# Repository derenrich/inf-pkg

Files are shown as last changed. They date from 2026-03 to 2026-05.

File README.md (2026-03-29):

# E-Ink RP2040 Driver Board with weird extras

View it at [kicanvas](https://kicanvas.org/?repo=https%3A%2F%2Fgithub.com%2Fderenrich%2Finf-pkg).

# Based off of RP2040 Minimal Design for JLCPCB
Based on [Minimal design example](https://datasheets.raspberrypi.com/rp2040/Minimal-KiCAD.zip) referenced in [Hardware design with RP2040: Using RP2040 microcontrollers to build boards and products](https://datasheets.raspberrypi.com/rp2040/hardware-design-with-rp2040.pdf).  Design updated for KiCAD 7 and manufacture/assembly at JLCPCB.

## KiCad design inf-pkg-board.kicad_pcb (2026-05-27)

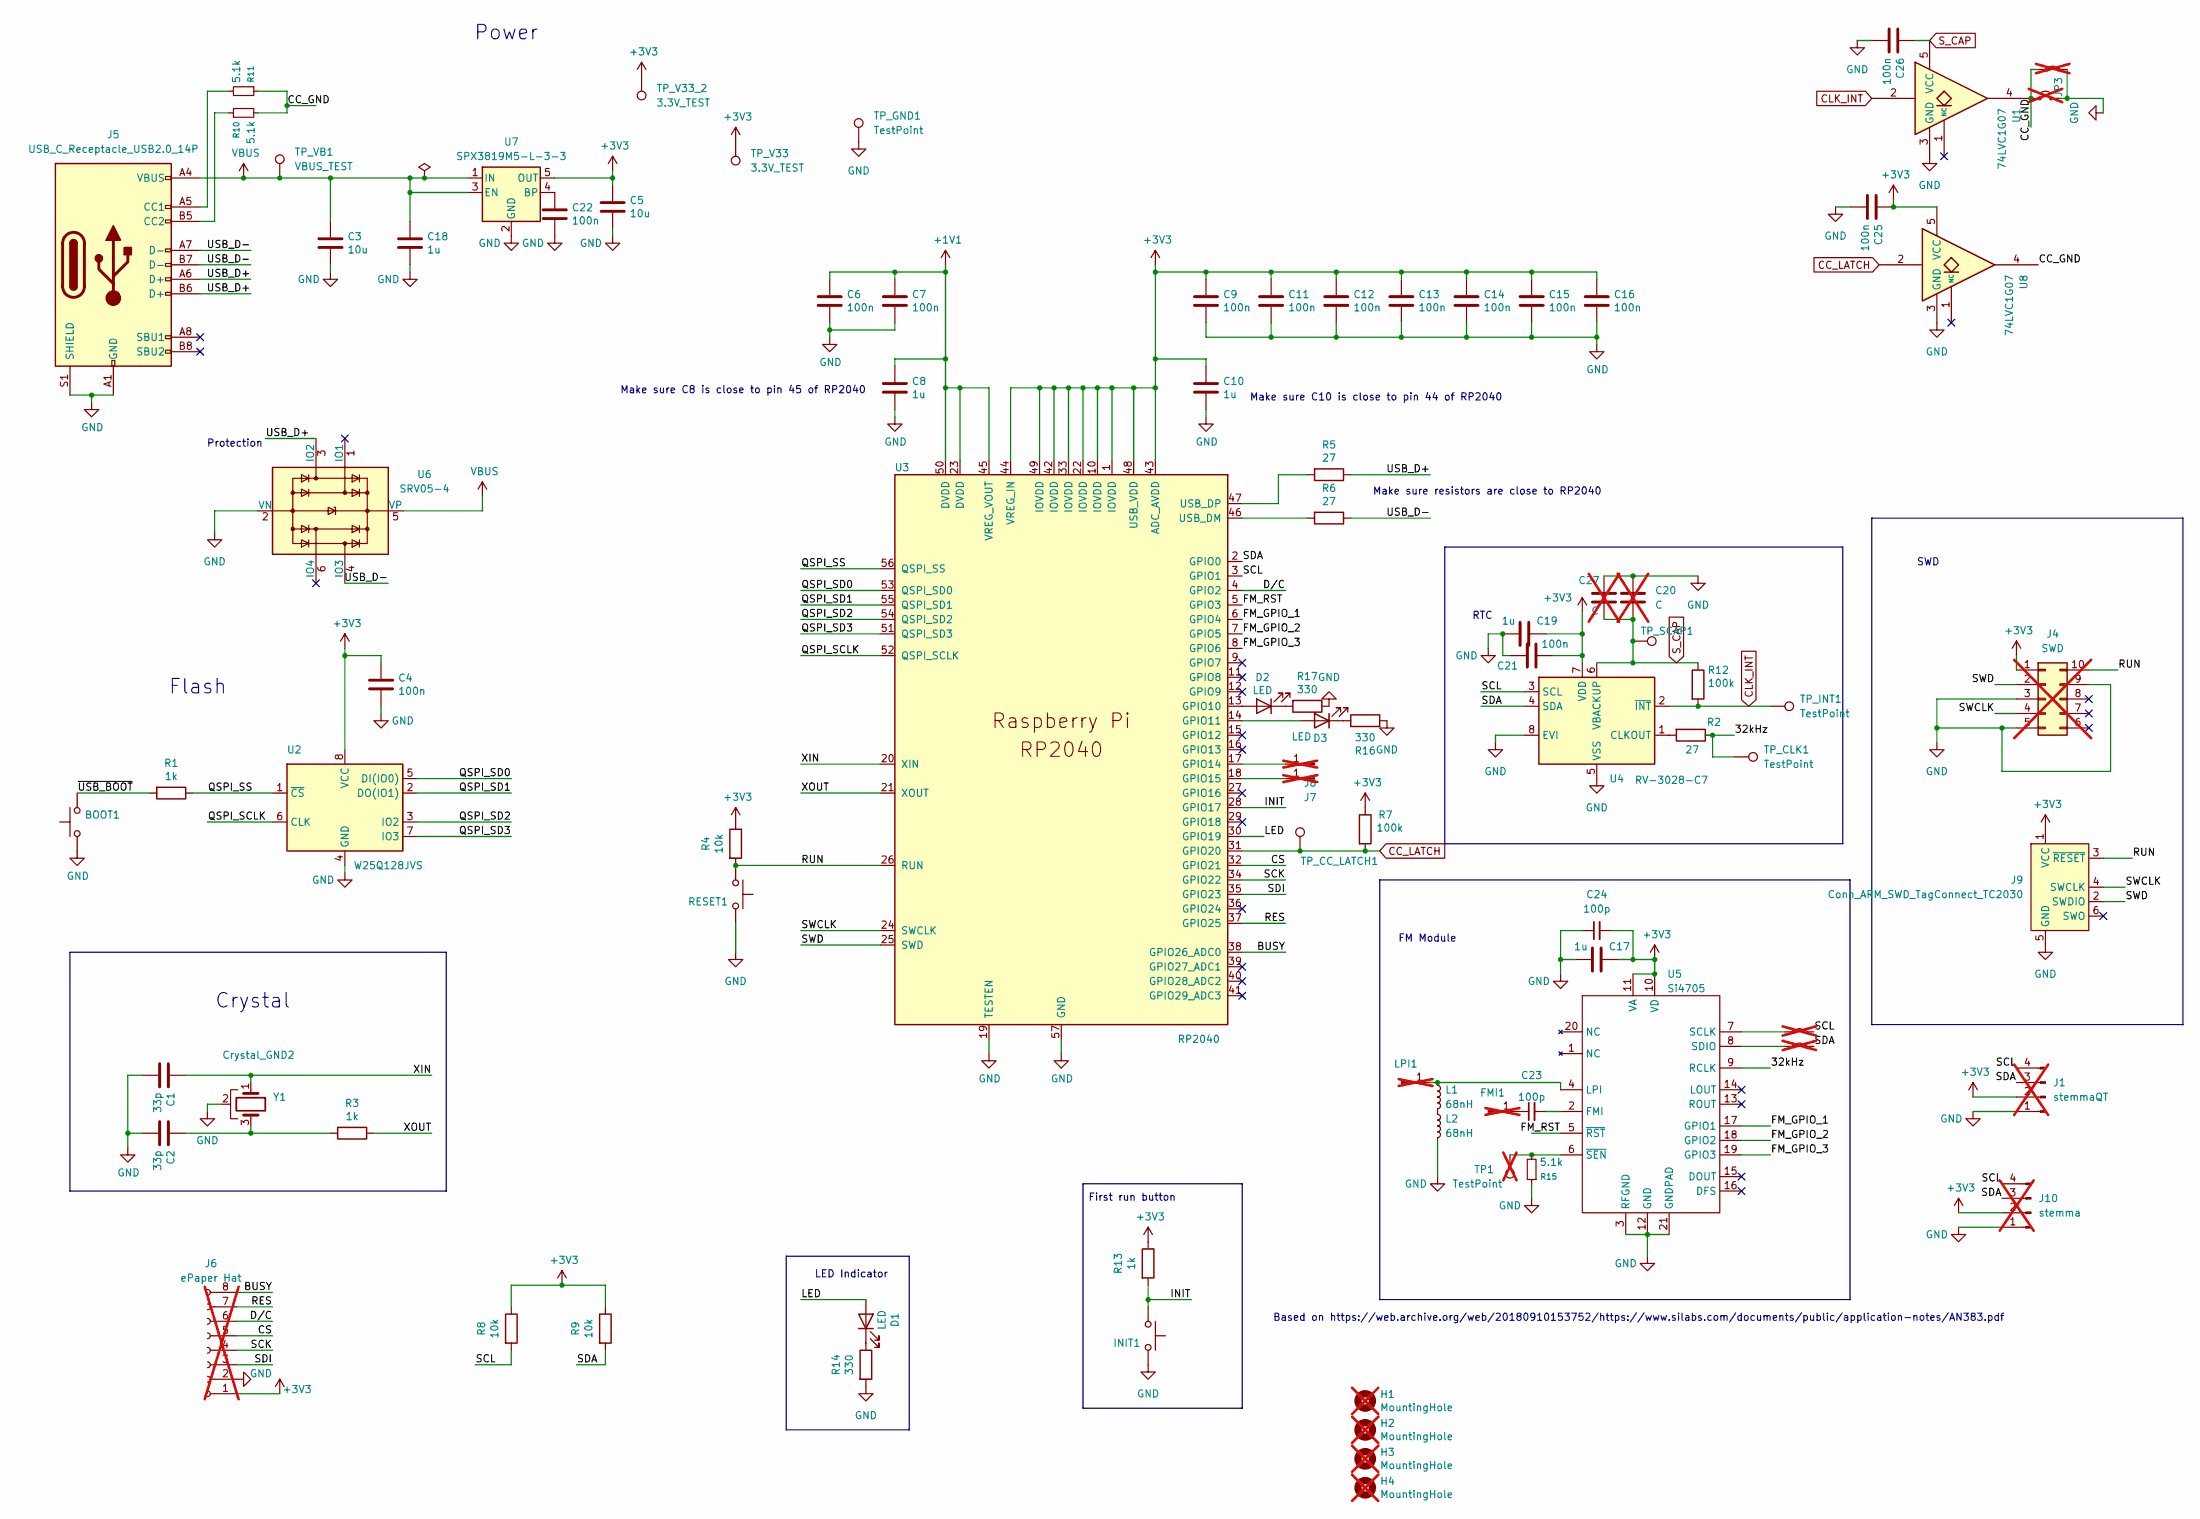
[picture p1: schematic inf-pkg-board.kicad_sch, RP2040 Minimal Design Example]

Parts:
BOOT1: TS-1088-AR02016; LCSC C720477
C1, C2: 33p; C_0402_1005Metric; LCSC C1562
C3, C5: 10u; C_0805_2012Metric; LCSC C15850
C4, C6, C7, C9, C11, C12, C13, C14, C15, C16, C21, C22, C25, C26: 100n; C_0402_1005Metric; LCSC C1525
C8, C10, C17, C18, C19: 1u; C_0402_1005Metric; LCSC C52923
C20: C; C_R21.00mm_P6.00mm; not fitted
C23, C24: 100p; C_0402_1005Metric; LCSC C1546
C27: C; C_Disc_D16.0mm_W5.0mm_P10.00mm; not fitted
D1, D2, D3: LED; D_0805_2012Metric; LCSC C84256
FMI1: Conn_01x01_Pin; PinHeader_1x01_P1.00mm_Vertical; not fitted
H1, H2, H3, H4: MountingHole; MountingHole_2.7mm_M2.5; not fitted
INIT1: TS-1088-AR02016; LCSC C720477
J1: stemmaQT; JST_PH_S4B-PH-K_1x04_P2.00mm_Horizontal; not fitted
J4: SWD; PinHeader_2x05_P1.27mm_Vertical_SMD; not fitted
J5: USB_C_Receptacle_USB2.0_14P; USB_C_Receptacle_G-Switch_GT-USB-7010ASV; LCSC C2988369
J6: ePaper Hat; PinHeader_1x08_P2.54mm_Vertical; not fitted
J7, J8: Conn_01x01_Pin; PinHeader_1x01_P2.54mm_Vertical; not fitted
J9: Conn_ARM_SWD_TagConnect_TC2030; Tag-Connect_TC2030-IDC-FP_2x03_P1.27mm_Vertical
J10: stemma; JST_PH_B4B-PH-K_1x04_P2.00mm_Vertical; not fitted
JP1, JP2: Jumper_2_Small_Bridged; SolderJumper-2_P1.3mm_Bridged_Pad1.0x1.5mm; not fitted
JP3: Jumper_2_Small_Open; PinHeader_1x02_P2.54mm_Vertical; not fitted
JP4: Jumper_2_Small_Bridged; SolderJumper-2_P1.3mm_Open_TrianglePad1.0x1.5mm; not fitted
L1, L2: 68nH; L_0603_1608Metric; LCSC C13415
LPI1: Conn_01x01_Pin; PinHeader_1x01_P2.54mm_Vertical; not fitted
R1, R3, R13: 1k; R_0402_1005Metric; LCSC C11702
R2, R5, R6: 27; R_0603_1608Metric; LCSC C25190
R4, R8, R9: 10k; R_0805_2012Metric; LCSC C17414
R7, R12: 100k; R_0402_1005Metric; LCSC C25741
R10, R11, R15: 5.1k; R_0402_1005Metric; LCSC C25905
R14, R16, R17: 330; R_0402_1005Metric; LCSC C25104
RESET1: TS-1088-AR02016; LCSC C720477
TP1: TestPoint; PinHeader_1x01_P1.00mm_Vertical; not fitted
TP_CC_LATCH1: TestPoint; TestPoint_Pad_D1.5mm
TP_CLK1: TestPoint; TestPoint_Pad_D1.5mm
TP_GND1: TestPoint; TestPoint_Pad_D1.5mm
TP_INT1: TestPoint; TestPoint_Pad_D1.5mm
TP_SCAP1: TestPoint; TestPoint_Pad_D2.5mm
TP_V33, TP_V33_2: 3.3V_TEST; TestPoint_Pad_D2.0mm
TP_VB1: VBUS_TEST; TestPoint_Pad_D2.0mm
U1, U8: 74LVC1G07; SOT-353_SC-70-5; LCSC C282345
U2: W25Q128JVS; SOIC-8_5.23x5.23mm_P1.27mm; LCSC C97521
U3: RP2040; RP2040-QFN-56; LCSC C2040
U4: RV-3028-C7; MicroCrystal_C7_SON-8_1.5x3.2mm_P0.9mm; LCSC C3019759
U5: Si4705; SiliconLabs_QFN-20-1EP_3x3mm_P0.5mm_EP1.8x1.8mm; LCSC C1526114
U6: SRV05-4; SOT-23-6; LCSC C85364
U7: SPX3819M5-L-3-3; SOT-23-5; LCSC C9055
Y1: Crystal_GND2; Crystal_SMD_3225-4Pin_3.2x2.5mm; LCSC C9002

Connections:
+1V1: C6.1, C7.1, C8.1, U3.23 (DVDD), U3.45 (VREG_VOUT), U3.50 (DVDD)
+3V3: C4.1, C5.1, C9.1, C10.1, C11.1, C12.1, C13.1, C14.1, C15.1, C16.1, C17.1, C19.1, C21.2, C24.2, C25.1, J1.2, J4.1, J6.1, J9.1 (VCC), J10.2, R4.1, R7.1, R8.1, R9.1, R13.1, TP_V33.1, TP_V33_2.1, U2.8 (VCC), U3.1 (IOVDD), U3.10 (IOVDD), U3.22 (IOVDD), U3.33 (IOVDD), U3.42 (IOVDD), U3.43 (ADC_AVDD), U3.44 (VREG_IN), U3.48 (USB_VDD), U3.49 (IOVDD), U4.7 (VDD), U5.10 (VD), U5.11 (VA), U7.5 (OUT), U8.5 (VCC)
/32kHz: R2.1, TP_CLK1.1, U5.9 (RCLK)
/BUSY: J6.8, U3.38 (GPIO26_ADC0)
/CC_GND: JP3.1 (A), JP4.1 (A), R10.2, R11.1, U1.4, U8.4
/CS: J6.5, U3.32 (GPIO21)
/D/C: J6.6, U3.4 (GPIO2)
/FM_GPIO_1: U3.6 (GPIO4), U5.17 (GPIO1)
/FM_GPIO_2: U3.7 (GPIO5), U5.18 (GPIO2)
/FM_GPIO_3: U3.8 (GPIO6), U5.19 (GPIO3)
/FM_RST: U3.5 (GPIO3), U5.5 (~RST)
/INIT: INIT1.1, R13.2, U3.28 (GPIO17)
/LED: D1.2 (A), U3.30 (GPIO19)
/QSPI_SCLK: U2.6 (CLK), U3.52 (QSPI_SCLK)
/QSPI_SD0: U2.5 (DI(IO0)), U3.53 (QSPI_SD0)
/QSPI_SD1: U2.2 (DO(IO1)), U3.55 (QSPI_SD1)
/QSPI_SD2: U2.3 (IO2), U3.54 (QSPI_SD2)
/QSPI_SD3: U2.7 (IO3), U3.51 (QSPI_SD3)
/QSPI_SS: R1.1, U2.1 (~CS), U3.56 (QSPI_SS)
/RES: J6.7, U3.37 (GPIO25)
/RUN: J4.10, J9.3 (~RESET), R4.2, RESET1.1, U3.26 (RUN)
/SCK: J6.4, U3.34 (GPIO22)
/SCL: J1.4, J10.4, JP1.2 (B), R8.2, U3.3 (GPIO1), U4.3 (SCL)
/SDA: J1.3, J10.3, JP2.2 (B), R9.2, U3.2 (GPIO0), U4.4 (SDA)
/SDI: J6.3, U3.35 (GPIO23)
/SWCLK: J4.4, J9.4 (SWCLK), U3.24 (SWCLK)
/SWD: J4.2, J9.2 (SWDIO), U3.25 (SWD)
/USB_D+: J5.A6 (D+), J5.B6 (D+), R5.1, U6.3 (IO2)
/USB_D-: J5.A7 (D-), J5.B7 (D-), R6.1, U6.4 (IO3)
/XIN: C1.1, U3.20 (XIN), Y1.1
/XOUT: R3.1, U3.21 (XOUT)
/~USB_BOOT: BOOT1.2, R1.2
CC_LATCH: R7.2, TP_CC_LATCH1.1, U3.31 (GPIO20), U8.2
CLK_INT: R12.2, TP_INT1.1, U1.2, U4.2 (~INT)
GND: BOOT1.1, C1.2, C2.2, C3.2, C4.2, C5.2, C6.2, C7.2, C8.2, C9.2, C10.2, C11.2, C12.2, C13.2, C14.2, C15.2, C16.2, C17.2, C18.2, C19.2, C20.1, C21.1, C22.2, C24.1, C25.2, C26.2, C27.1, INIT1.2, J1.1, J4.3, J4.5, J4.9, J5.A1 (GND), J5.A12 (GND), J5.B1 (GND), J5.B12 (GND), J5.S1 (SHIELD), J6.2, J9.5 (GND), J10.1, JP3.2 (B), JP4.2 (B), L2.2, R14.2, R15.1, R16.2, R17.1, RESET1.2, TP_GND1.1, U1.3 (GND), U2.4 (GND), U3.19 (TESTEN), U3.57 (GND), U4.5 (VSS), U4.8 (EVI), U5.3 (RFGND), U5.12 (GND), U5.21 (GNDPAD), U6.2 (VN), U7.2 (GND), U8.3 (GND), Y1.2
unnamed: C2.1, R3.2, Y1.3
unnamed: D1.1 (K), R14.1
unnamed: D2.2 (A), U3.13 (GPIO10)
unnamed: D2.1 (K), R17.2
unnamed: D3.2 (A), U3.14 (GPIO11)
unnamed: D3.1 (K), R16.1
unnamed: C23.1, FMI1.1
unnamed: J5.A5 (CC1), R11.2
unnamed: J5.B5 (CC2), R10.1
unnamed: J7.1, U3.18 (GPIO15)
unnamed: J8.1, U3.17 (GPIO14)
unnamed: JP1.1 (A), U5.7 (SCLK)
unnamed: JP2.1 (A), U5.8 (SDIO)
unnamed: L1.2, L2.1
unnamed: L1.1, LPI1.1, U5.4 (LPI)
unnamed: R6.2, U3.46 (USB_DM)
unnamed: R5.2, U3.47 (USB_DP)
unnamed: R2.2, U4.1 (CLKOUT)
unnamed: C23.2, U5.2 (FMI)
unnamed: R15.2, TP1.1, U5.6 (~SEN)
unnamed: C22.1, U7.4 (BP)
S_CAP: C20.2, C26.1, C27.2, R12.1, TP_SCAP1.1, U1.5 (VCC), U4.6 (VBACKUP)
VBUS: C3.1, C18.1, J5.A4 (VBUS), J5.A9 (VBUS), J5.B4 (VBUS), J5.B9 (VBUS), TP_VB1.1, U6.5 (VP), U7.1 (IN), U7.3 (EN)

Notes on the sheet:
First run button
FM Module
Make sure C8 is close to pin 45 of RP2040
SWD
Protection
Make sure C10 is close to pin 44 of RP2040
Crystal
Power
RTC
Based on https://web.archive.org/web/20180910153752/https://www.silabs.com/documents/public/application-notes/AN383.pdf
Flash
Make sure resistors are close to RP2040
LED Indicator

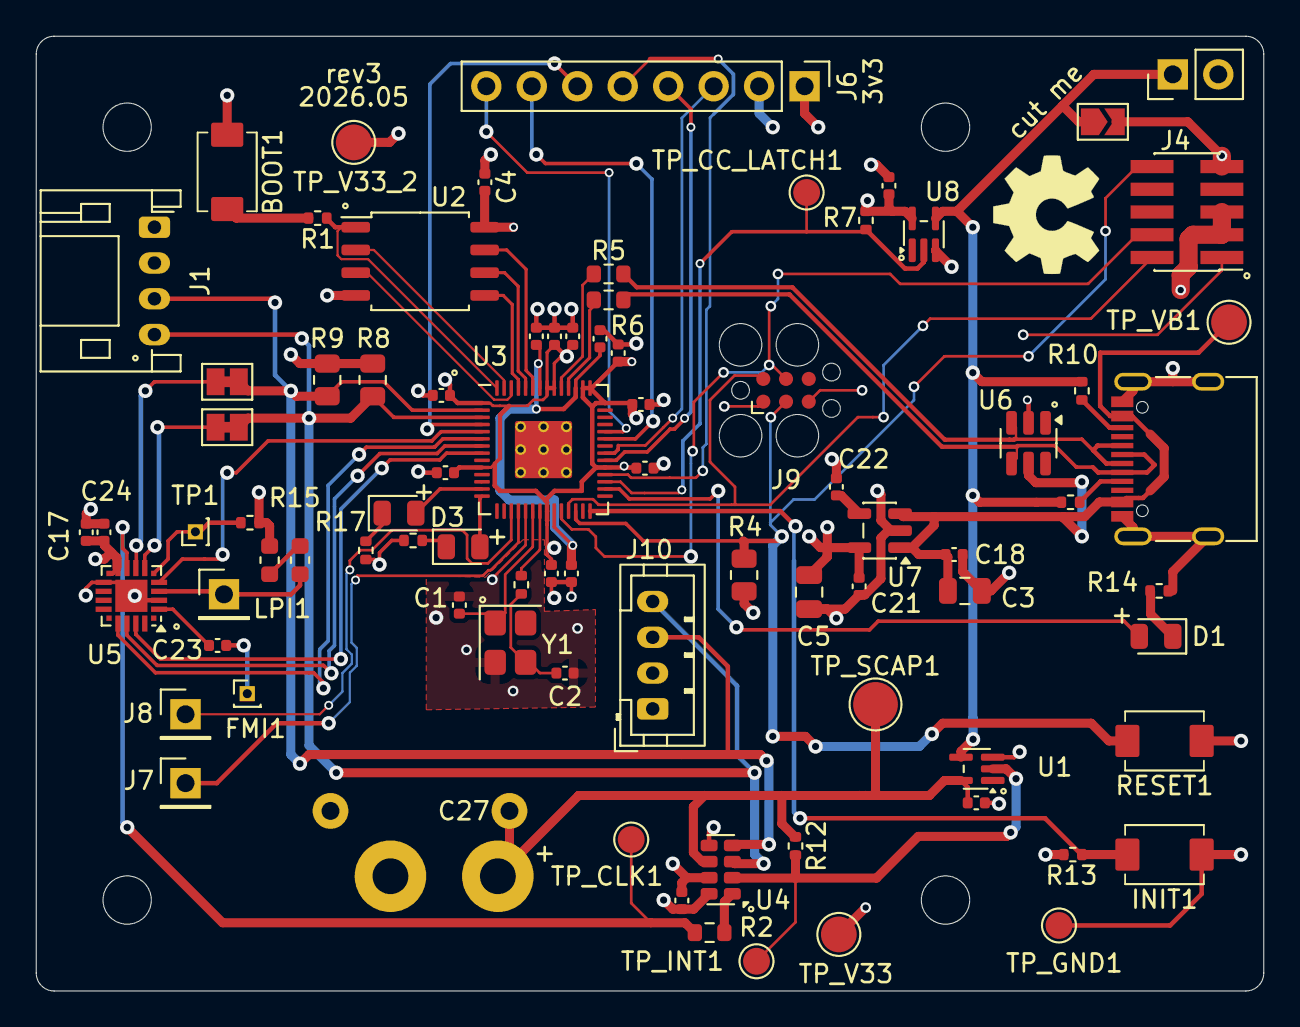
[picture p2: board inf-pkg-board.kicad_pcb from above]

Board: 4 copper layers, 68.6 x 53.3 mm, 88 parts (1 on the bottom side), 58 nets.

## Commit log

2026-02-14 my version
    [RP2040_minimal.kicad_pcb, RP2040_minimal.kicad_sch, inf-pkg-board.kicad_pcb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]
2026-03-28 fix bom error / add debug pads
    [inf-pkg-board.kicad_pcb, inf-pkg-board.kicad_sch]
2026-03-29 bom optimization
    [inf-pkg-board.kicad_pcb, inf-pkg-board.kicad_sch]
2026-03-29 more ground
    [inf-pkg-board.kicad_pcb]
2026-04-01 final tweaks
    [inf-pkg-board.kicad_pcb, inf-pkg-board.kicad_sch]
2026-04-01 swap resistor to smaller/standard size
    [inf-pkg-board.kicad_pcb, inf-pkg-board.kicad_sch]
